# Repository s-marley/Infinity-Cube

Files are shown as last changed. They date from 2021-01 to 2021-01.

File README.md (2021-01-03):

# Infinity-Cube
A small infinity cube programmed with FastLED. The cube, stand and electronics box are 3D printed, fusion and STL files can be found in the Fusion360 folder. The patterns are generated using the FastLED library, code can be found in the LEDCube folder.
This project uses tiny LED strips which can be found here:
- [Adafruit (US)](https://www.adafruit.com/product/4368)
- [PiHut (UK)](https://thepihut.com/products/ultra-skinny-neopixel-1515-led-strip-4mm-wide)
- [Alibaba (Worldwide)](https://ipixelleds.en.alibaba.com/product/1600100606010-801743685/4mm_Width_Tiny_ultra_thin_SMD1515_75leds_m_Addressable_LED_Strip_light.html)

## YouTube Video

LED Cube (https://www.youtube.com/watch?v=gbqNV-nmTS4)

## Wiring and connections
The wiring for the project is very simple and is shown below. The resistor and capacitor are recommended but optional.

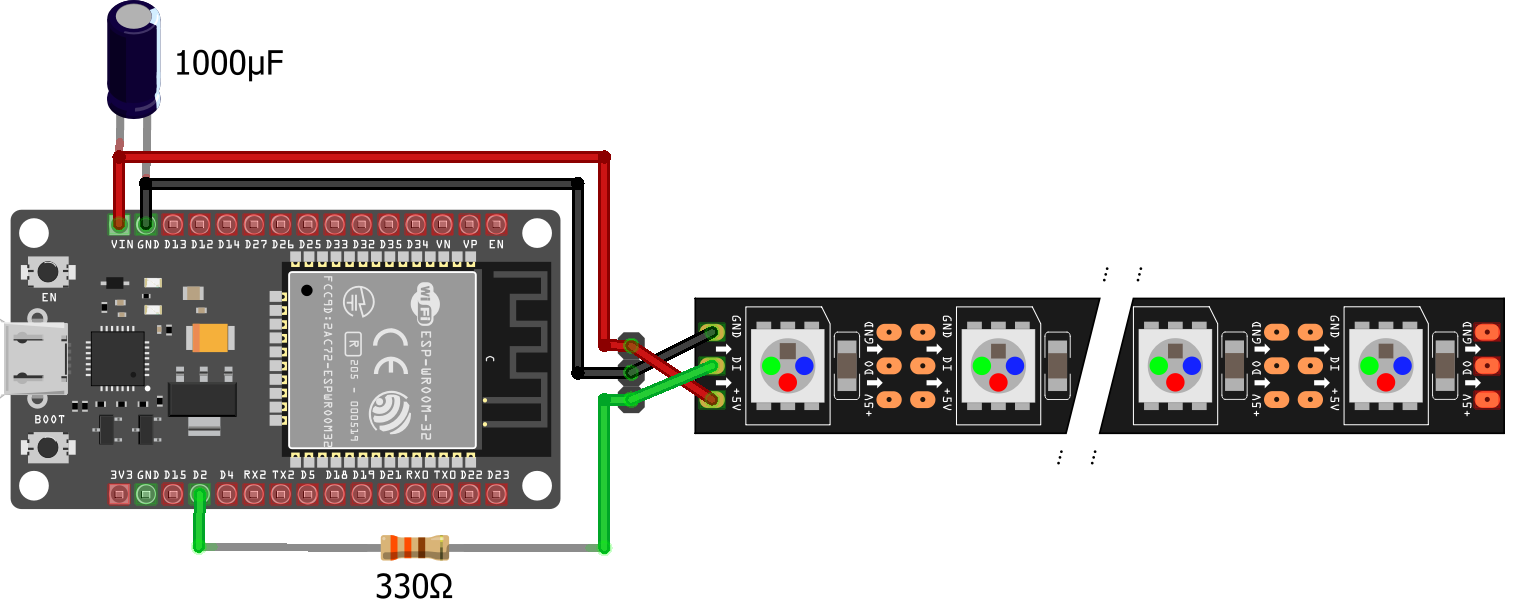
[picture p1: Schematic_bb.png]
Schematic

The diagram below shows how the segments of the cube are connected together. Pink circles are the segment numbers. Green arrows show where the data line has to be run back underneath a strip. Wiring enters the cube through the rear-left.
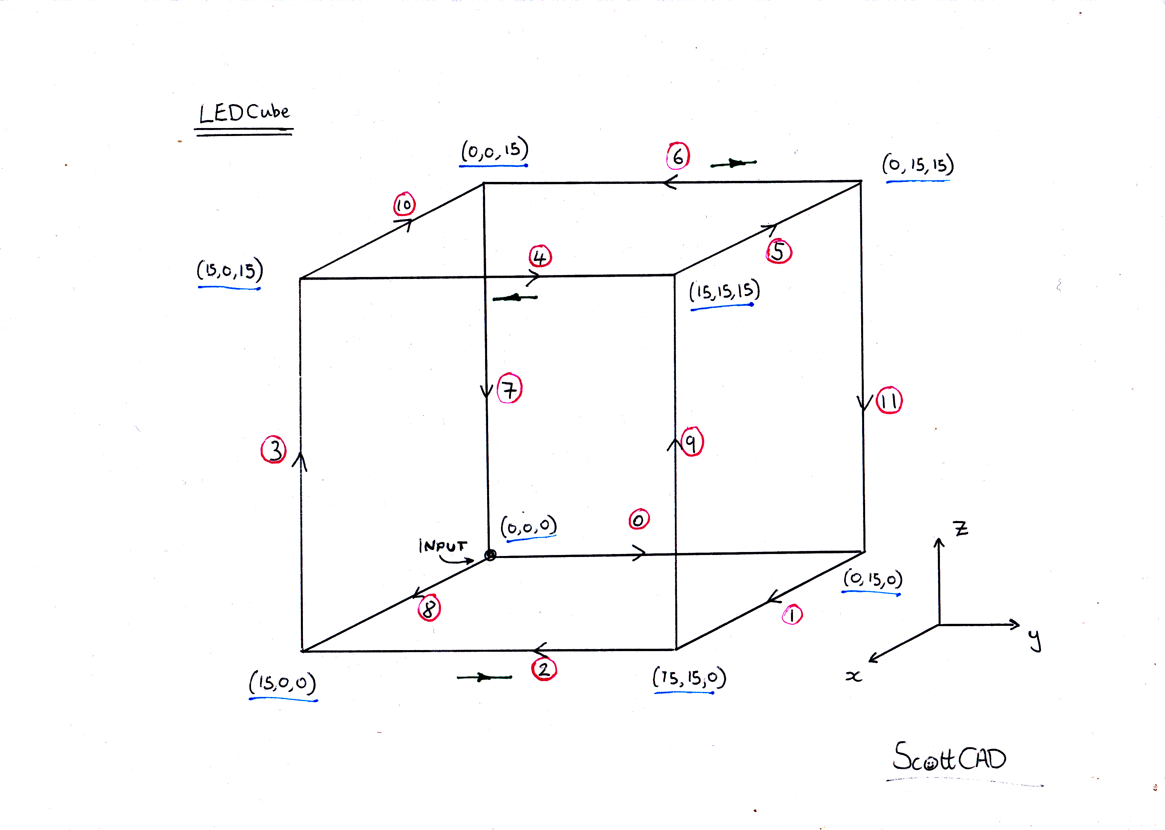
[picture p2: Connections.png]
Connections


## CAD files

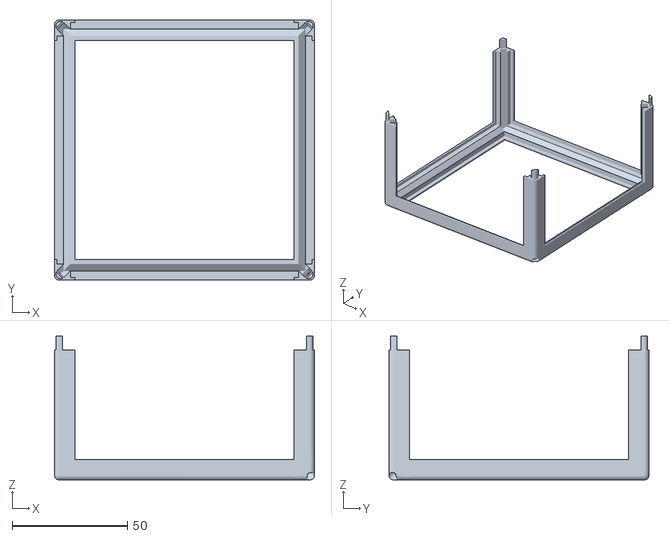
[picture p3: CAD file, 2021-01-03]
Fusion360/Cube Bottom.stl
112.7 x 112.7 x 62.3

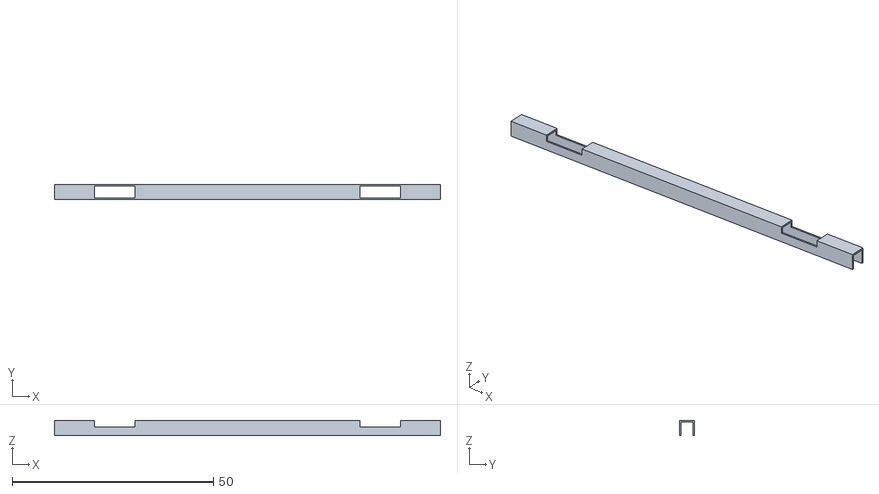
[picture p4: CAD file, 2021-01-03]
Fusion360/Cube Insert.stl
96.0 x 3.80 x 3.80

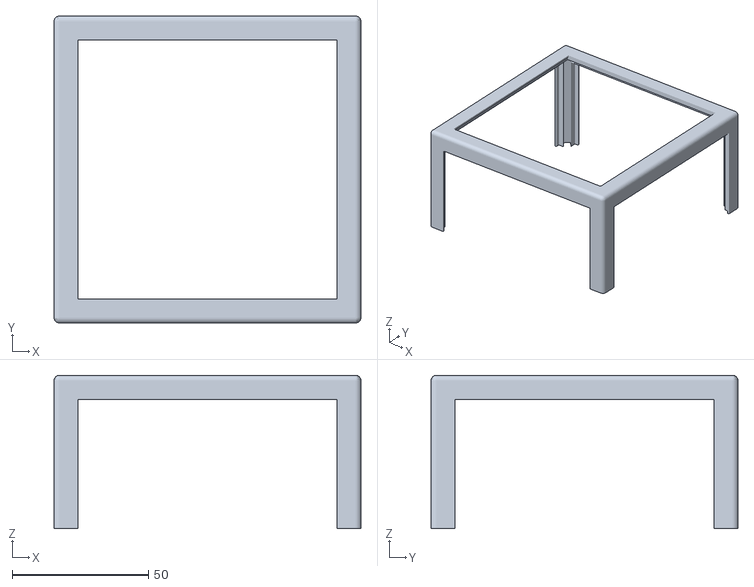
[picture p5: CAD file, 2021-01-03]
Fusion360/Cube Top.stl
112.7 x 112.7 x 56.3

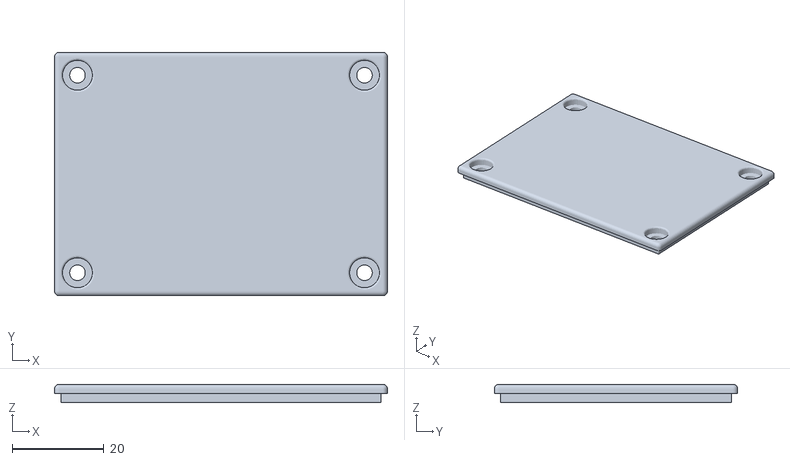
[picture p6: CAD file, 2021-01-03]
Fusion360/Electronics Lid.stl
72.5 x 53.0 x 4.00

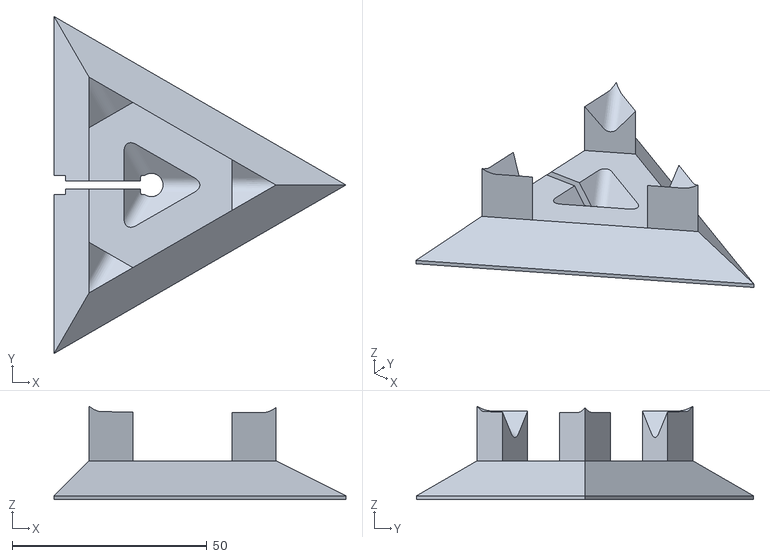
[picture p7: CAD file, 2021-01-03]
Fusion360/Stand.stl
75.0 x 86.6 x 24.0

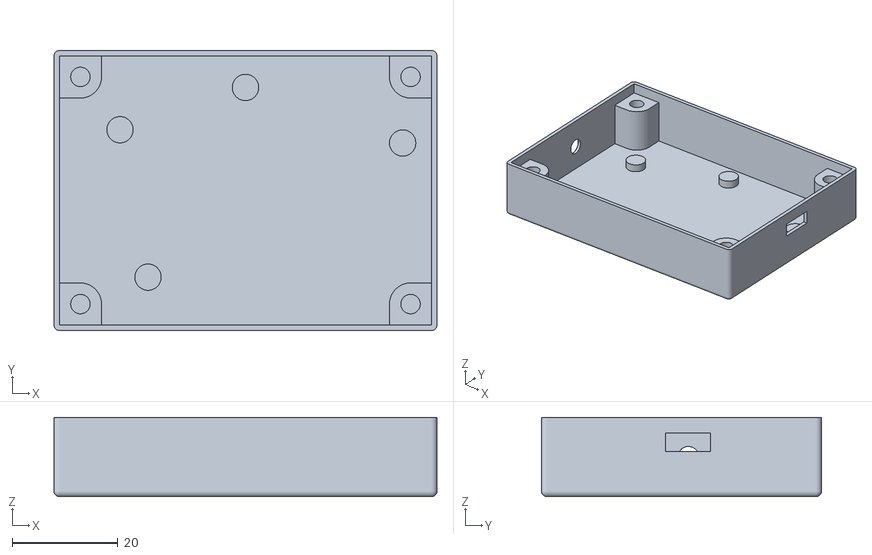
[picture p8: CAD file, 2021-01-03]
Fusion360/Electronics Base.stl
72.5 x 53.0 x 15.0

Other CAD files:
Fusion360/LEDCube Electronics.f3d
Fusion360/LEDCube Stand.f3d
Fusion360/LEDCube.f3d

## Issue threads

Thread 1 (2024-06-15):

Update WLED to Aid Functionality

Stewie-040882, 2024-06-15:
I dont know if youre aware, but using WLED you can enter the lights section, and using only 1 pin, you can break 1 long led strip into multiple segments by dictating how many leds make 1 segment..

Also, as a side note, i would make the base plate the housing, for the esp32, so you would have the display cube, and remove it for better apperance

Great work by the way, i thought the idea was amazing!!

s-marley, 2024-06-15:
Yeah absolutely. I have used WLED for [other projects](https://www.youtube.com/watch?v=9iJQhOiL2bk&t=2s), I just quite enjoy writing my own patterns and raw FastLED is much quicker to write and iterate on than recompiling WLED with a custon FX.cpp each time. I'm trying to remember why I didn't build the controller into the base, there was a reason back then but it escapes me now! Thank you for your comment :)

Stewie-040882, 2024-06-15:
Cool, sorry, just when you mentioned WLED, but ive just rewatched the section referencing WLED.. shame really about the 10 segments, but i know those Neopixel leds use the same logic (1 continuous strip), and was figuring it would save time coding (as i can only read code lol).

i was picturing the cube with 12 strips showing the 3d fireworks.

I know you mentioned you like your own code, which i respect, someone with coding knowledge could be able to modify their opensource code. or request more segments on their github.

apologies as im sure youve considered this option. Im still going to attempt a build of your project at some point, but think ill try with the larger leds first as i know it will be extremely tricky to get it all to fit

s-marley, 2024-06-15:
No problem, just doing what I think is fun :) and yes, if you're going to make your own, I'd definitely start with a bigger version, those tiny LEDs were a right pain even for someone who has a bit of experience in this area. Good luck!

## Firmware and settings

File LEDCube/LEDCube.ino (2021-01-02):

#include <FastLED.h>

#define LED_PIN               2
#define LEDS_PER_SEGMENT      14
#define SEGMENTS              12
#define BRIGHTNESS            200
#define NUM_LEDS              LEDS_PER_SEGMENT * SEGMENTS
#define NUM_LEDS_WITH_SAFETY  NUM_LEDS + 1

CRGB source1[NUM_LEDS_WITH_SAFETY];
CRGB source2[NUM_LEDS_WITH_SAFETY];
CRGB output[NUM_LEDS_WITH_SAFETY];

uint8_t blendAmount = 0;
uint8_t patternCounter = 0;
uint8_t source1Pattern = 0;
uint8_t source2Pattern = 1;
bool useSource1 = false;

void setup() {
  FastLED.addLeds<WS2812B, LED_PIN, GRB>(output, NUM_LEDS_WITH_SAFETY);
  FastLED.setBrightness(BRIGHTNESS);
  Serial.begin(57600);
}

void loop() {
  EVERY_N_MILLISECONDS(10) {
    blend(source1, source2, output, NUM_LEDS, blendAmount);   // Blend between the two sources

    if (useSource1) {
      if (blendAmount < 255) blendAmount++;                   // Blend 'up' to source 2
    } else {
      if (blendAmount > 0) blendAmount--;                     // Blend 'down' to source 1
    }
  }

  EVERY_N_SECONDS(8) {
    nextPattern();
  }

  runPattern(source1Pattern, source1);                  // Run both patterns simultaneously
  runPattern(source2Pattern, source2);
  
  FastLED.show();
}

void nextPattern() {
  patternCounter = (patternCounter + 1) % 5;

  if (useSource1) source1Pattern = patternCounter;
  else source2Pattern = patternCounter;

  useSource1 = !useSource1;
}

void runPattern(uint8_t pattern, CRGB *LEDarray) {
  switch (pattern) {
    case 0:
      rainbowComet(LEDarray);
      break;
    case 1:
      prettyNoise(LEDarray);
      break;
    case 2:
      randomStar(LEDarray);
      break;
    case 3:
      fillRainbow(LEDarray);
      break;
    case 4:
      pixels(LEDarray);
      break;
  }
}

uint8_t xyz(uint8_t x, uint8_t y, uint8_t z) {

  /* The coordinates of the edges run from 0 - 15. Each edge only has 14 'real' pixels,
   * so there are only LEDs from 1 - 14. The vertices (corners) are missing.
   * If one of these vertices is requested, return a safe pixel that is not displayed.
   * We do the same for coordinates that are inside the cube i.e. not on an edge.
   */
  
  uint8_t lps = LEDS_PER_SEGMENT;
  uint8_t safePx = NUM_LEDS;

  if ((x == 0 || x == lps + 1) && (y == 0 || y == lps + 1) && (z == 0 || z == lps + 1)) return safePx;

  // z-direction edges
  if (x == 0        && y == 0)        return (8 * lps)  - z;      // Seg 7
  if (x == 0        && y == lps + 1)  return (12 * lps) - z;      // Seg 11
  if (x == lps + 1  && y == 0)        return (3 * lps)  + z - 1;  // Seg 3
  if (x == lps + 1  && y == lps + 1)  return (9 * lps)  + z - 1;  // Seg 9

  // y-direction edges
  if (x == 0        && z == 0)        return y - 1;               // Seg 0
  if (x == 0        && z == lps + 1)  return (7 * lps)  - y;      // Seg 6
  if (x == lps + 1  && z == 0)        return (3 * lps)  - y;      // Seg 2
  if (x == lps + 1  && z == lps + 1)  return (4 * lps)  + y - 1;  // Seg 4

  // x-direction edges
  if (y == 0        && z == 0)        return (8 * lps)  + x - 1;  // Seg 8
  if (y == 0        && z == lps + 1)  return (11 * lps) - x;      // Seg 10
  if (y == lps + 1  && z == 0)        return lps        + x - 1;  // Seg 1
  if (y == lps + 1  && z == lps + 1)  return (6 * lps)  - x;      // Seg 5

  // If none of the above, we have an invalid coordinate
  return safePx;
}

//------------ Patterns below ------------//

void pixels(CRGB *LEDarray) {
  static uint8_t pos = 0;
  static uint8_t a = 0;
  static uint8_t b = 0;

  // Fill all pixels and blend them together
  for (int c = 0; c <= LEDS_PER_SEGMENT + 1; c++) {
    LEDarray[xyz(a,b,c)] = blend(LEDarray[xyz(a,b,c)], CRGB::Orange, 128);
    LEDarray[xyz(a,c,b)] = blend(LEDarray[xyz(a,c,b)], CRGB::Magenta, 128);
    LEDarray[xyz(c,a,b)] = blend(LEDarray[xyz(c,a,b)], CRGB::Blue, 128);
  }

  EVERY_N_MILLISECONDS(33) {    
    // Coordinates moving around a square
    if(pos < 15) a++;
    else if (pos <= (LEDS_PER_SEGMENT * 2) + 1) b++;
    else if (pos <= (LEDS_PER_SEGMENT * 3) + 2) a--;
    else b--;

    // Start again one we reach the end of the square
    pos = (pos + 1) % ((LEDS_PER_SEGMENT + 1) * 4);
  }

  fadeToBlackBy(LEDarray, NUM_LEDS, 10);
  
}

void fillRainbow(CRGB *LEDarray) {
  static uint8_t pos = 0;
  
  uint8_t noise = inoise8(millis()/5);
  fill_rainbow(LEDarray, LEDS_PER_SEGMENT, noise, 10);

  // Copy to other segments
  for (int i = 0; i < SEGMENTS; i++) {
    memmove8(&LEDarray[LEDS_PER_SEGMENT * i], &LEDarray[0], LEDS_PER_SEGMENT * sizeof(CRGB));
  }

  // White dots moving up and down vertical pillars
  LEDarray[xyz(0, 0, LEDS_PER_SEGMENT - pos)] = CRGB::White;
  LEDarray[xyz(0, LEDS_PER_SEGMENT + 1, pos)] = CRGB::White;
  LEDarray[xyz(LEDS_PER_SEGMENT + 1, LEDS_PER_SEGMENT + 1, LEDS_PER_SEGMENT - pos)] = CRGB::White;
  LEDarray[xyz(LEDS_PER_SEGMENT + 1, 0, pos)] = CRGB::White;

  EVERY_N_MILLISECONDS(20) {
    pos = (pos + 1) % LEDS_PER_SEGMENT;
  }
}

void rainbowComet(CRGB *LEDarray) {
  static uint8_t easeOutVal = 0;
  static uint8_t easeInVal  = 0;

  // Make pattern appear over two segments
  uint8_t ledsPerSegment = LEDS_PER_SEGMENT * 2;
  uint8_t segments = SEGMENTS / 2;

  easeOutVal = ease8InOutQuad(easeInVal);
  easeInVal++;

  uint8_t pos = lerp8by8(0, ledsPerSegment, easeOutVal);
  uint8_t hue =  map(pos, 0, ledsPerSegment, 0, 230);
  
  LEDarray[pos] = CHSV(hue, 255, 255);
  fadeToBlackBy(LEDarray, ledsPerSegment, 20);

  // Copy to other segments
  for (int i = 0; i < segments; i++) {
    memmove8(&LEDarray[ledsPerSegment * i], &LEDarray[0], ledsPerSegment * sizeof(CRGB));
  }
}

void randomStar(CRGB *LEDarray) {
  EVERY_N_MILLISECONDS(75) {
    LEDarray[random16(0, NUM_LEDS)] = CRGB::LightGrey;
  }


  for (int i = 0; i < NUM_LEDS; i++) {
    
    // Brightness
    uint8_t bNoise = inoise8(i * 100, millis());
    bNoise = constrain(bNoise, 50, 200);
    bNoise = map(bNoise, 50, 200, 20, 80);

    // Hue
    uint8_t hNoise = inoise8(i * 20, millis() / 5);
    hNoise = constrain(hNoise, 50, 200);
    hNoise = map(hNoise, 50, 200, 160, 192);
    
    if (LEDarray[i].g == 0) {
      LEDarray[i] = CHSV(hNoise, 255, bNoise);
    }
  }
  
  fadeToBlackBy(LEDarray, NUM_LEDS, 5);
}


void prettyNoise(CRGB *LEDarray) {
  fill_noise16 (LEDarray, NUM_LEDS, 1, 0, 100, 1, 1, 50, millis() / 3, 5);
}
